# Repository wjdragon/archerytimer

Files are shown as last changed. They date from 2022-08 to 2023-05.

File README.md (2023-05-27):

# archerytimer
Arduino-driven archery timer with buzzer

This project runs an archery time using an arduino uno and a custom 7-segment LED display using WS8211 LEDs 

Project Organization
-----------------------------------
This project is split into multiple files.  The Arduino IDE is pretty good about multi-file projects by placing them into
separate .ino files but bringing everything together into a single IDE.  A brief description about each of project files is as follows:

GLOBAL: Sets up forward and global declarations, all the required Arduino pins, all the buttons to be used

SETUP: Standard Arduino setup() function.  SSD1306 OLED display, ezButton initialization

LOOP: Standard Arduino loop() function.  We use the TimedAction library to perform "threading", and these threads are called here.

BUTTON: All button related functions are implemented here.  Short and long press actuation logic found here.

TIMER: All timer related functions are implemented here.  This thread is setup to trigger at 1HZ.  The value on the displayed clock is decremented here

ALARM: All alarm (whistle) related functions are implemented here.  The alarm uses a state machine to determine when to sound on and off.  Since the trigger is 250ms, the alarm is defaulted to stay on or off until the next trigger.  The number of "blasts" is determined by a global variable.

DISPLAY: All 7-segment display logic is implemented here.

GFX: All graphics related functions are implemented here.

## Hardware
This project uses the following hardware:
- Arduino Uno board
- WS2811 LEDs (12v) arranged into 8-digit displays (times 3).
- Two MAX485 chips for long distance communication
- 120dB alarm (3v, 5v, or 12v)
- PN2222A

If using a short (less than 1 meter) run from the Arduino to LED board, the signal should be strong enough.  Anything longer and the signal will degrade.  For this project, we use a 30ft 8-wire cable to connect the controller box (Arduino) to the LED display panel.  However, the signal gets too weak and needs to be boosted.  See schematic

To wire the seven segment display, please note that each segment takes 6 LEDs of the WS8211.  However, since one IC controls 3 LEDs, from the FastLED perspect it is two (2) LEDs per segment (physically, 6 are lit up).  To see how the 7-segment should be built withe the LED strip, look at the g_DISPLAY.ino file for comments on which segments are lit up.  A quick ASCII drawing below here is also provided.  Note that the wiring comes into the display from LEFT CENTER, loops around the figure, and exits RIGHT CENTER.

```
    3
  4   2
->  1  ->
  5   7
    6
```

## Use
+10/-10 seconds to adjust the time needed for one end
"Start" will blast two whistles and put 10s on the timer.  At the end of the 10s, it will blast one whistle and display the time for the end, which will sound three whistles.  Clicking again will "Stop" the countdown, the clock will freeze, and the unit is in idle state.  No whistles are blasted if the timer is stopped prematurely.
"3/5" whistle: Pressing once will blast three whistles to immediately end the round and stop the timer. The clock will not reset.  Holding this button will blast 5 whistles and stop the timer.  The clock will not reset.
"Reset Clock" will stop the timer and reset the clock
"AB/CD" will toggle the LEDs for line 1 or line 2.

For tournaments with two lines:
Press "Start/Start" to start the AB line.
- if an archer looks to burn the time, allow the clock to finish and blast the three whistles.  Clicking "Start" again will start the 10s countdown and allow CD line to approach
- if all archers finish early, press "Start/Stop" to stop the countdown.  Click "Reset Clock" to reset the clock.  Click "Start/Stop" to start the 10s countdown for CD line.  3 whistles will not be issued in this way.

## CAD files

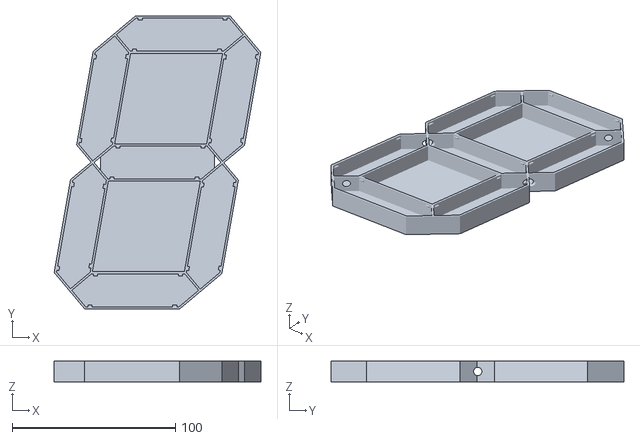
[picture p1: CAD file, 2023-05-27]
ArcheryTimer v1.0/SevenSegment.stl
126.8 x 179.6 x 12.7

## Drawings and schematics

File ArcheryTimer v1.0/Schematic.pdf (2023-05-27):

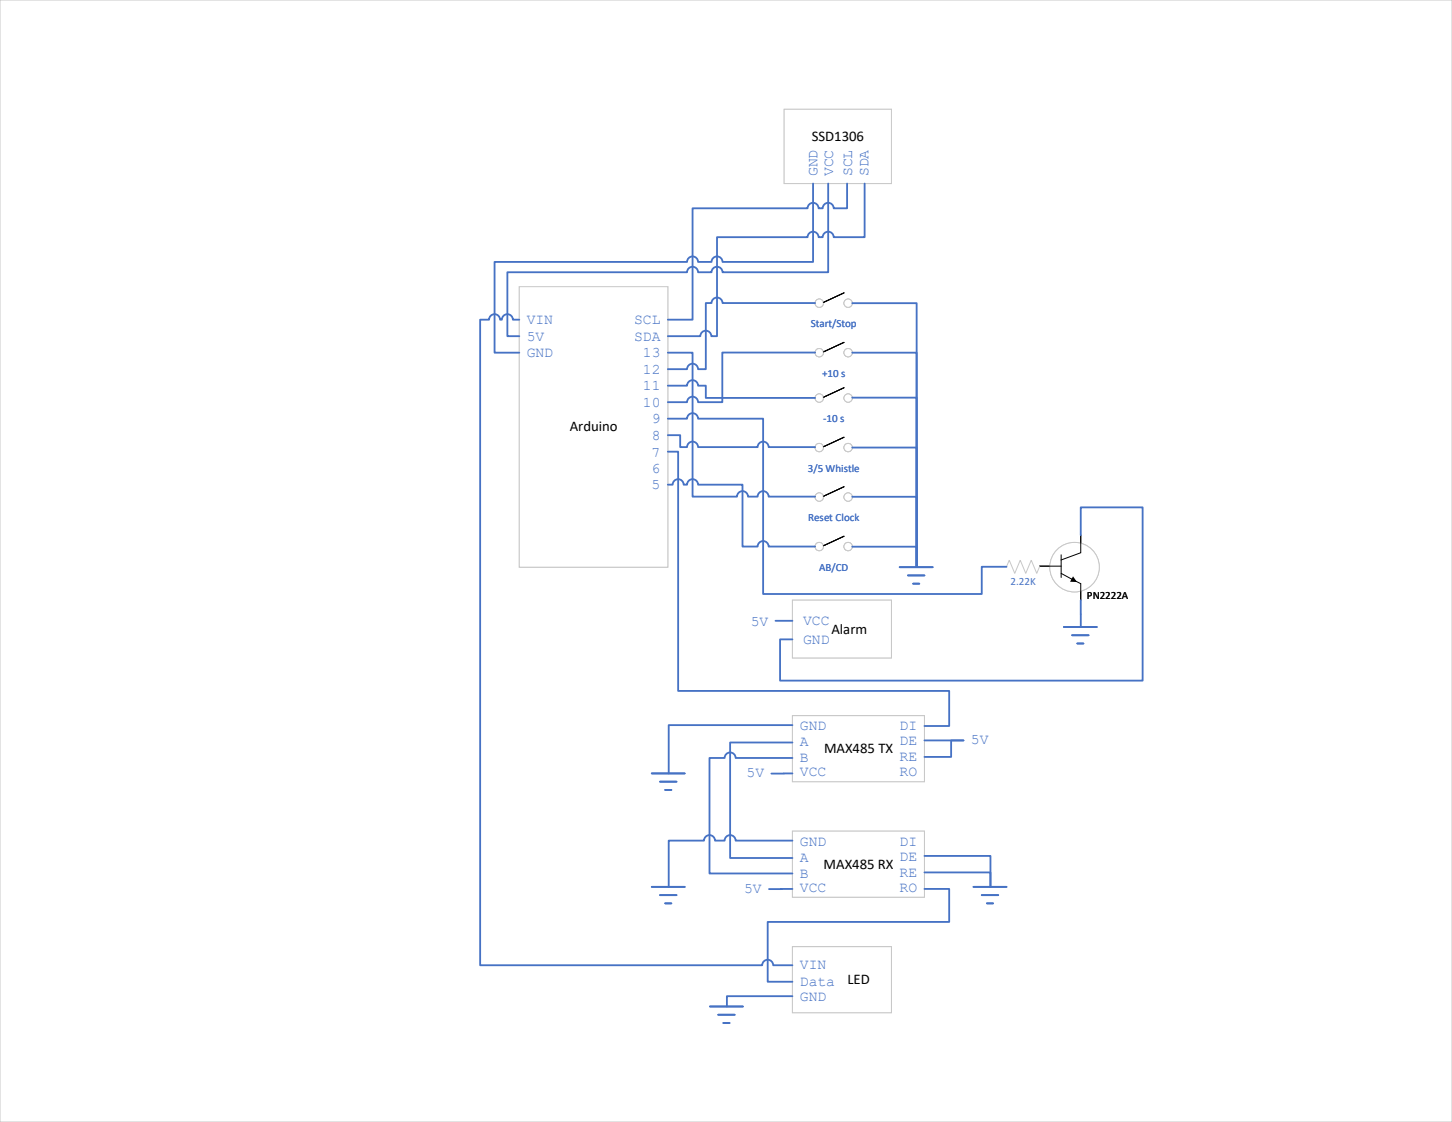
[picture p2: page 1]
Arduino; VIN 5V GND; SCL SDA 13 12 11 10 9 8 7 6 5; MAX485 TX; GND A B VCC; MAX485 RX; Start/Stop; 3/5 Whistle; Reset Clock; Alarm VCC; GND; LED; VIN Data GND

SSD1306 GND VCC SCL SDA

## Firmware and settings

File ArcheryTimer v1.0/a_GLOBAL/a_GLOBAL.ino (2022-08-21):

#include <SPI.h>
#include <Wire.h>
#include <Adafruit_GFX.h>
#include <Adafruit_SSD1306.h>
#include <ezButton.h>
#include <TimedAction.h>

const int SHORT_PRESS_TIME = 250;
const int LONG_PRESS_TIME = 500;

//GPIO declarations
//-=-=-=-=-=-=-=-=-=-=-=-=-=-=-=-=-=-=-=-=-=-=-=-=
byte segmentClock = 6;    //Yellow
byte segmentLatch = 5;    //Brown
byte segmentData = 7;     //Blue
byte alarmInPin = 8;
byte alarmOutPin = 9;     //Green
byte timeAddPin = 10;
byte timeMinusPin = 11;
byte startStopPin = 12;
byte resetPin = 13;

#define SCREEN_WIDTH 128 // OLED display width, in pixels
#define SCREEN_HEIGHT 32 // OLED display height, in pixels
#define OLED_RESET     -1 // Reset pin # (or -1 if sharing Arduino reset pin)
#define SCREEN_ADDRESS 0x3C ///< See datasheet for Address; 0x3D for 128x64, 0x3C for 128x32

//Button Declarations
ezButton btnAlarm(alarmInPin);
ezButton btnTimeAdd(timeAddPin);
ezButton btnTimeMinus(timeMinusPin);
ezButton btnStartStop(startStopPin);
ezButton btnReset(resetPin);

enum runningState {
  STOPPED,
  PREPARE,
  RUNNING,
};

enum alarmState {
  ACTIVE,
  INACTIVE,
};

//Global Variables
int countdown = 120;             //keeps the qualifier clock value.  Only changes when user sets clock time
int runclk = 0;                 //keeps the end clock value.  Decrements when the clock is running
int prepclk = 10;               //keeps the 10s prep clock value.  Decrements when the clock is running
int alarmCount;                 //number of beeps for the alarm cycle
alarmState alarmStatus = INACTIVE;
runningState runStatus = STOPPED;

//Forward Function Declarations
void updateTime();
void runAlarm();
void button_check(void);
void showNumber(float value);
void centerText(String text);

//TimedAction Declarations
TimedAction timerAction = TimedAction(1000,updateTime);
TimedAction alarmAction = TimedAction(250,runAlarm);

//GFX Display
Adafruit_SSD1306 display(SCREEN_WIDTH, SCREEN_HEIGHT, &Wire, OLED_RESET);

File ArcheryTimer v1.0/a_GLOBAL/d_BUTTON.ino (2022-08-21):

/* Process buttons in order of importance:
    1. Alarm
    2. Start/Stop
    3. Timer adjust

    Timer adjust will only function when the state machine is stopped.
*/

void button_check(void)
{
  long pressDuration;

  btnAlarm.loop();
  btnTimeAdd.loop();
  btnTimeMinus.loop();
  btnStartStop.loop();
  btnReset.loop();

  /* Check and act on alarm button */
  if (btnAlarm.isPressed()) {
    btnAlarm.pressTime = millis();
    btnAlarm.isPressing = true;
    btnAlarm.isLongDetected = false;
  }
  if (btnAlarm.isReleased()) {
    btnAlarm.isPressing = false;
    btnAlarm.releaseTime = millis();
    pressDuration = btnAlarm.releaseTime - btnAlarm.pressTime;
    if (pressDuration < SHORT_PRESS_TIME)
      if (!btnAlarm.isLongDetected)
      {
        alarmCount = 3;
        runStatus = STOPPED;
      }
  }
  if (btnAlarm.isPressing && !btnAlarm.isLongDetected) {
    pressDuration = millis() - btnAlarm.pressTime;
    if (pressDuration > LONG_PRESS_TIME) {
      btnAlarm.isLongDetected = true;
    }
  }

  //actively pressing and long press is true
  if (btnAlarm.isPressing && btnAlarm.isLongDetected) {
    digitalWrite(alarmOutPin, HIGH);    //5 whistle blast and reset everything
    runStatus = STOPPED;
  } else if (!btnAlarm.isPressing && btnAlarm.isLongDetected) {
    digitalWrite(alarmOutPin, LOW);
    showNumber(countdown);
    alarmCount = 0;
    btnAlarm.isLongDetected = false;    //btn released, alarm is stopped, reset long state
  }

  /* Check and act on start/stop button */
  if (btnStartStop.isPressed()) {
    btnStartStop.pressTime = millis();
    btnStartStop.isPressing = true;
    btnStartStop.isLongDetected = false;
  }
  if (btnStartStop.isReleased()) {
    btnStartStop.isPressing = false;
    btnStartStop.releaseTime = millis();
    pressDuration = btnStartStop.releaseTime - btnStartStop.pressTime;
    if (pressDuration < SHORT_PRESS_TIME)
    {
      switch (runStatus)
      {
        case STOPPED:
          runStatus = PREPARE;
          runclk = countdown;   //set the running timer
          prepclk = 10;
          alarmCount = 2;
          Serial.print("State is PREPARE.  Timer is set to ");
          Serial.println(runclk);
          break;
        case PREPARE:
          runStatus = STOPPED;
          Serial.println("State is STOPPED");
          break;
        case RUNNING:
          runStatus = STOPPED;
          Serial.println("State is STOPPED");
          break;
      }
    }
  }

  if (runStatus == STOPPED)   //only allow timer adjustments if we're in STOPPED state
  {
    /* Check and act on time plus button */
    if (btnTimeAdd.isPressing && btnTimeAdd.isLongDetected) {   //handle long press
      countdown = (countdown + 10 >= 990 ? 990 : countdown + 10);
      showNumber(countdown);
      delay(100);
    }
    if (btnTimeAdd.isPressed()) {
      btnTimeAdd.pressTime = millis();
      btnTimeAdd.isPressing = true;
      btnTimeAdd.isLongDetected = false;
    }
    if (btnTimeAdd.isReleased()) {
      btnTimeAdd.isPressing = false;
      btnTimeAdd.releaseTime = millis();
      pressDuration = btnTimeAdd.releaseTime - btnTimeAdd.pressTime;
      if (pressDuration < SHORT_PRESS_TIME) {
        countdown = (countdown + 10 >= 990 ? 990 : countdown + 10);
        showNumber(countdown);
      }
    }
    if (btnTimeAdd.isPressing && !btnTimeAdd.isLongDetected) {
      pressDuration = millis() - btnTimeAdd.pressTime;
      if (pressDuration > LONG_PRESS_TIME) {
        btnTimeAdd.isLongDetected = true;
      }
    }

    /* Check and act on time minus button */
    if (btnTimeMinus.isPressing && btnTimeMinus.isLongDetected) {
      countdown = (countdown - 10 <= 10 ? 10 : countdown - 10);
      showNumber(countdown);
      delay(100);
    }
    if (btnTimeMinus.isPressed()) {
      btnTimeMinus.pressTime = millis();
      btnTimeMinus.isPressing = true;
      btnTimeMinus.isLongDetected = false;
    }
    if (btnTimeMinus.isReleased()) {
      btnTimeMinus.isPressing = false;
      btnTimeMinus.releaseTime = millis();
      pressDuration = btnTimeMinus.releaseTime - btnTimeMinus.pressTime;
      if (pressDuration < SHORT_PRESS_TIME) {
        countdown = (countdown - 10 <= 10 ? 10 : countdown - 10);
        showNumber(countdown);
      }
    }
    if (btnTimeMinus.isPressing && !btnTimeMinus.isLongDetected) {
      pressDuration = millis() - btnTimeMinus.pressTime;
      if (pressDuration > LONG_PRESS_TIME) {
        btnTimeMinus.isLongDetected = true;
      }
    }
  }//End runStatus == STOPPED

  //Handle Reset button.  Reset state, display, kill alarm, etc
  if (btnReset.isPressed()) {
      runStatus = STOPPED;
      showNumber(countdown);
      alarmCount = 0;
    }
}

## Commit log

2023-05-27 Added schematic
2023-05-27 Added STL for 7-Segment
    [SevenSegment.stl]
